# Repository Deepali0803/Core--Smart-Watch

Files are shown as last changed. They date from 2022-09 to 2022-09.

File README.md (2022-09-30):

# Core--Smart-Watch
This is a design of development board for SmartWatch, designed in Eagle Autodesk with SMD and through-hole components.
It is capable of performing some basic functions such as digital read/write, analog signals, I2C and UART communications, with Bluetooth connection, RTC(real-time clock), and OLED display to set alarm and operate easily.

The power consumption in sleep mode is very low, around 1.3mA so the battery could last 2 days.

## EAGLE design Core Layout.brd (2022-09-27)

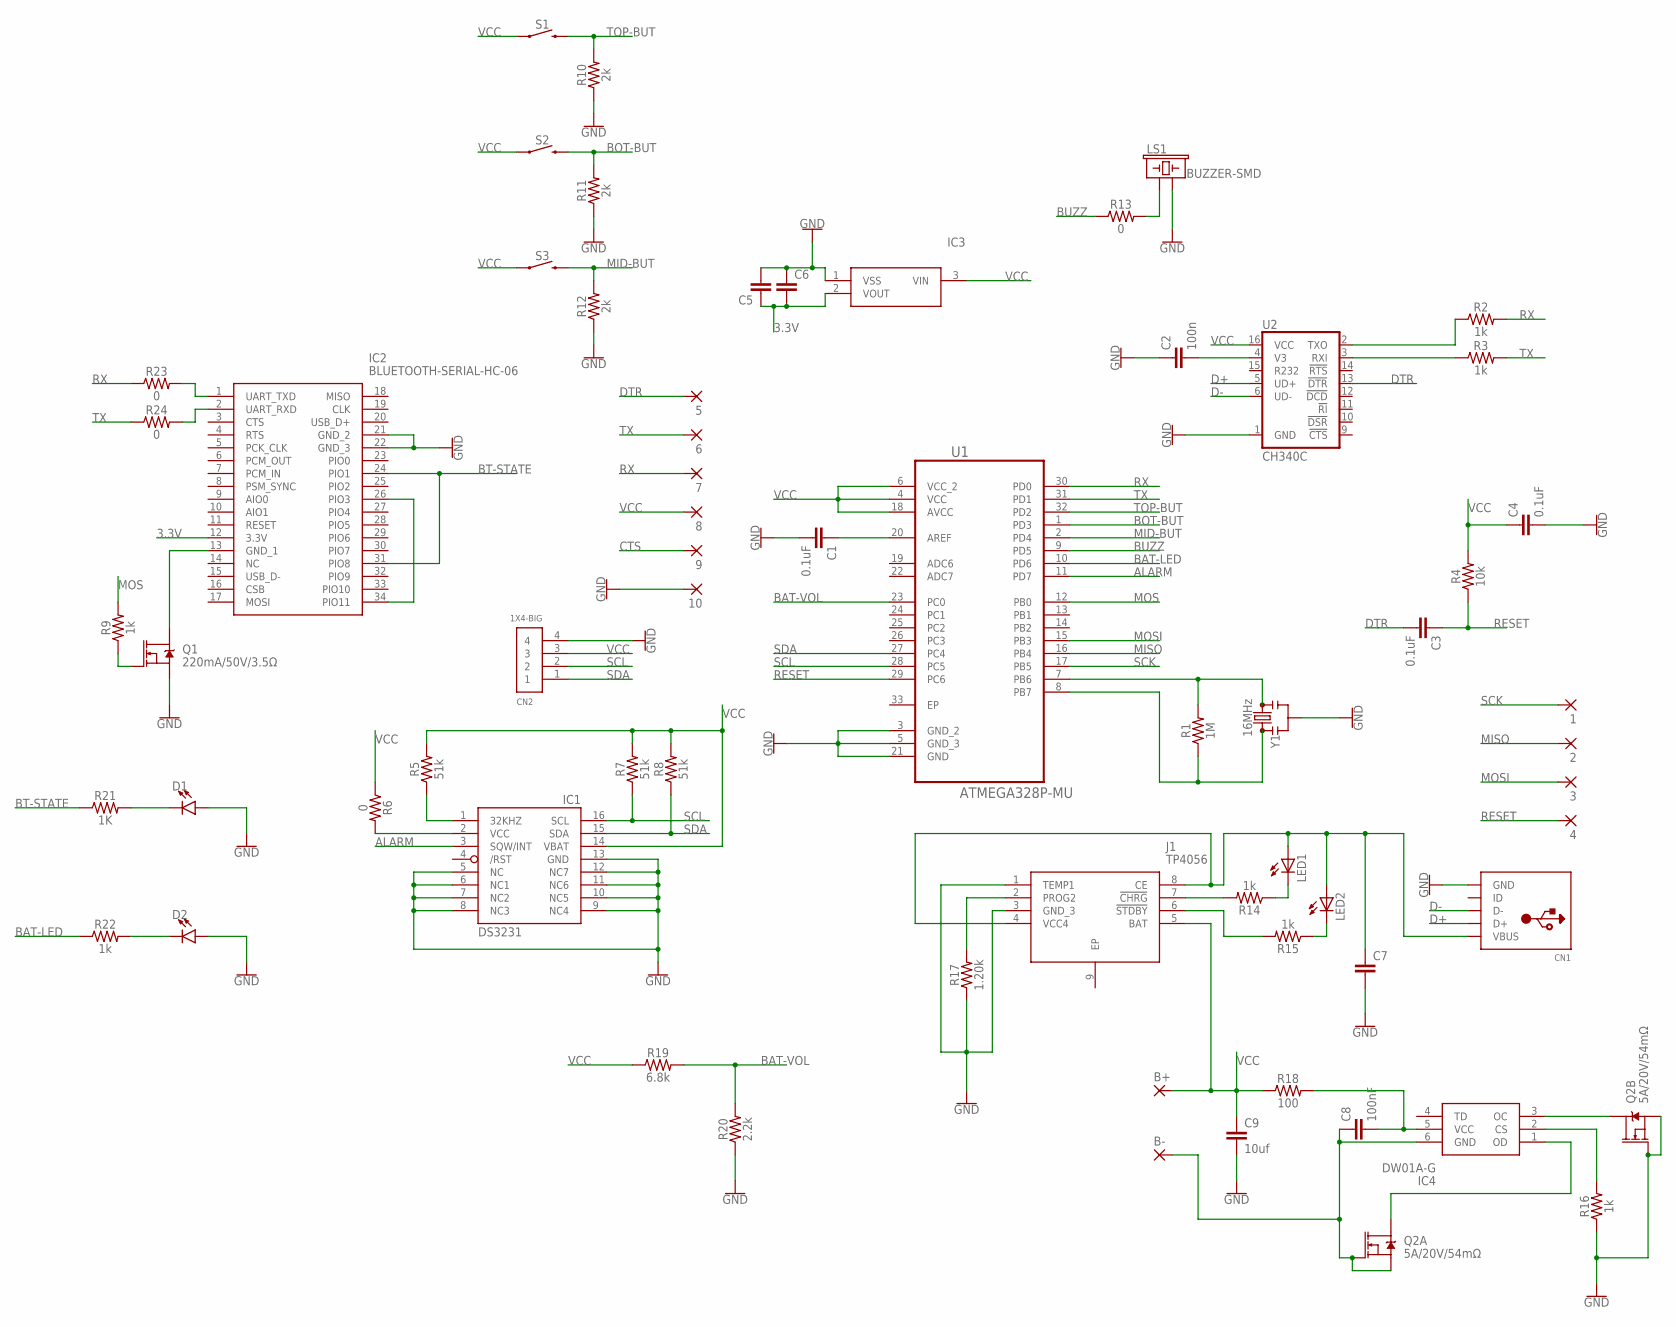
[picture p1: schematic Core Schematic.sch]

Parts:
1, 2, 3, 4, 5, 6, 7, 8, 9, 10: SMD2; SMD1,27-2,54
B+: SMD2; SMD1,27-2,54
B-: SMD2; SMD1,27-2,54
C1, C3, C4: 0.1uF; 0603
C2: 100n; 0603
C5, C6, C7: 4.7PF-0603-50V-5%; 0603
C8: 100nF; 0603
C9: 10uf; 0603
CN1: USBMINIB; USB-MINIB
CN2: 1X4-BIG; 1X04-BIG
D1, D2: LED0603; LED-0603
IC1: DS3231/SO; SO16W
IC2: BLUETOOTH-SERIAL-HC-06; BLUETOOTHSERIALHC06
IC3: XC6206P332MR; SOT95P280X130-3N
IC4: DW01A-G; SOT95P280X135-6N
J1: TP4056; SOIC127P600X175-9N
LED1, LED2: LEDCHIPLED_0805; CHIPLED_0805
LS1: BUZZER-SMD; BUZZER-CCV
Q1: 220mA/50V/3.5Ω; SOT23-3
Q2: 5A/20V/54mΩ; MICROFET_2X2
R1: 1M; 0603
R2, R3, R9, R14, R15, R16, R22: 1k; 0603
R4: 10k; 0603
R5, R7, R8: 51k; 0603
R6, R13, R23, R24: 0; 0603
R10, R11, R12: 2k; 0603
R17: 1.20k; 0603
R18: 100; 0603
R19: 6.8k; 0603
R20: 2.2k; 0603
R21: 1K; 0603
S1, S2, S3: MOMENTARY-SWITCH-SPST-SMD-6.0X3.5MM; TACTILE_SWITCH_SMD_6.0X3.5MM
U1: ATMEGA328P-MU; QFN50P500X500X100-33N
U2: CH340C; SO016
Y1: 16MHz; RESONATOR-SMD-3.2X1.3

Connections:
3.3V: C5.1, C6.2, IC2.12 (3.3V), IC3.2 (VOUT)
ALARM: IC1.3 (SQW/INT), U1.11 (PD7)
BAT-LED: R22.1, U1.10 (PD6)
BAT-VOL: R19.2, R20.2, U1.23 (PC0)
BOT-BUT: R11.2, S2.2, U1.1 (PD3)
BT-STATE: IC2.24 (PIO1), IC2.31 (PIO8), R21.1
BUZZ: R13.1, U1.9 (PD5)
CTS: 9.1
D+: CN1.D+, U2.5 (UD+)
D-: CN1.D-, U2.6 (UD-)
DTR: 5.1, C3.2, U2.13 (!DTR)
GND: 10.1, C1.2, C2.1, C4.2, C5.2, C6.1, C7.2, C9.2, CN1.GND, CN2.4, D1.A, D2.A, IC1.5 (NC), IC1.6 (NC1), IC1.7 (NC2), IC1.8 (NC3), IC1.9 (NC4), IC1.10 (NC5), IC1.11 (NC6), IC1.12 (NC7), IC1.13 (GND), IC2.21 (GND_2), IC2.22 (GND_3), IC3.1 (VSS), J1.1 (TEMP1), J1.3 (GND_3), LS1.- (2), Q1.2 (S), Q2.G2 (G), Q2.S2 (S), R10.1, R11.1, R12.1, R16.1, R17.1, R20.1, U1.3 (GND_2), U1.5 (GND_3), U1.21 (GND), U2.1 (GND), Y1.2
MID-BUT: R12.2, S3.2, U1.2 (PD4)
MISO: 2.1, U1.16 (PB4)
MOS: R9.2, U1.12 (PB0)
MOSI: 3.1, U1.15 (PB3)
unnamed: C1.1, U1.20 (AREF)
unnamed: IC1.1 (32KHZ), R5.1
unnamed: R1.2, U1.7 (PB6), Y1.3
unnamed: R1.1, U1.8 (PB7), Y1.1
unnamed: IC1.2 (VCC), R6.2
unnamed: IC2.13 (GND_1), Q1.3 (D)
unnamed: C2.2, U2.4 (V3)
unnamed: R3.1, U2.3 (RXI)
unnamed: Q1.1 (G), R9.1
unnamed: LS1.+ (1), R13.2
unnamed: R2.1, U2.2 (TXO)
unnamed: J1.6 (!STDBY), R15.2
unnamed: LED2.C, R15.1
unnamed: J1.7 (!CHRG), R14.2
unnamed: LED1.C, R14.1
unnamed: C7.1, CN1.VBUS, J1.4 (VCC4), J1.8 (CE), LED1.A, LED2.A
unnamed: C8.2, IC4.5 (VCC), R18.2
unnamed: B-.1, C8.1, IC4.6 (GND), Q2.G1 (G), Q2.S1 (S)
unnamed: J1.2 (PROG2), R17.2
unnamed: D2.C, R22.2
unnamed: D1.C, R21.2
unnamed: IC2.26 (PIO3), IC2.34 (PIO11)
unnamed: IC4.3 (OC), Q2.D2 (D), Q2.D2_2 (D)
unnamed: IC4.2 (CS), R16.2
unnamed: IC2.1 (UART_TXD), R23.2
unnamed: IC4.1 (OD), Q2.D1 (D), Q2.D1_2 (D)
unnamed: IC2.2 (UART_RXD), R24.2
RESET: 4.1, C3.1, R4.1, U1.29 (PC6)
RX: 7.1, R2.2, R23.1, U1.30 (PD0)
SCK: 1.1, U1.17 (PB5)
SCL: CN2.2, IC1.16 (SCL), R7.1, U1.28 (PC5)
SDA: CN2.1, IC1.15 (SDA), R8.1, U1.27 (PC4)
TOP-BUT: R10.2, S1.2, U1.32 (PD2)
TX: 6.1, R3.2, R24.1, U1.31 (PD1)
VCC: 8.1, B+.1, C4.1, C9.1, CN2.3, IC1.14 (VBAT), IC3.3 (VIN), J1.5 (BAT), R4.2, R5.2, R6.1, R7.2, R8.2, R18.1, R19.1, S1.1, S2.1, S3.1, U1.4 (VCC), U1.6 (VCC_2), U1.18 (AVCC), U2.16 (VCC)

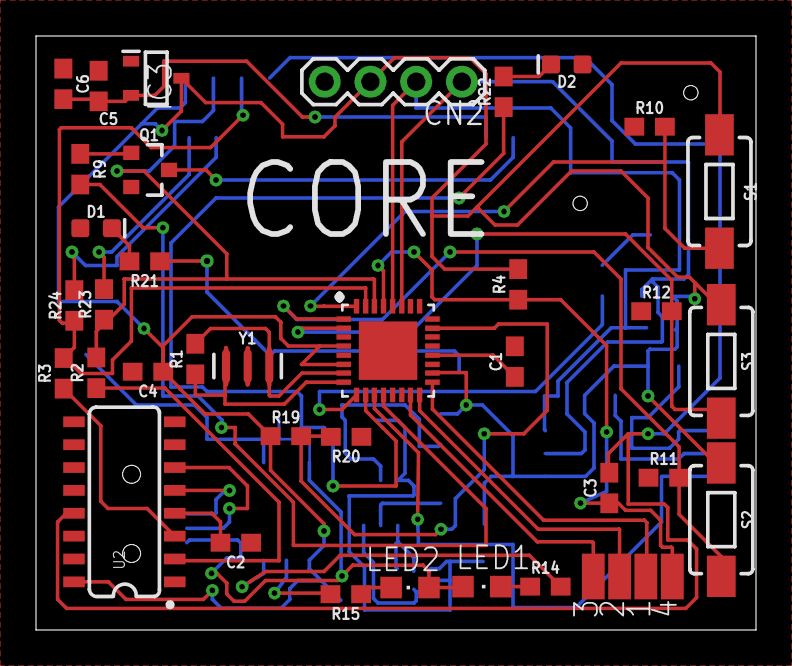
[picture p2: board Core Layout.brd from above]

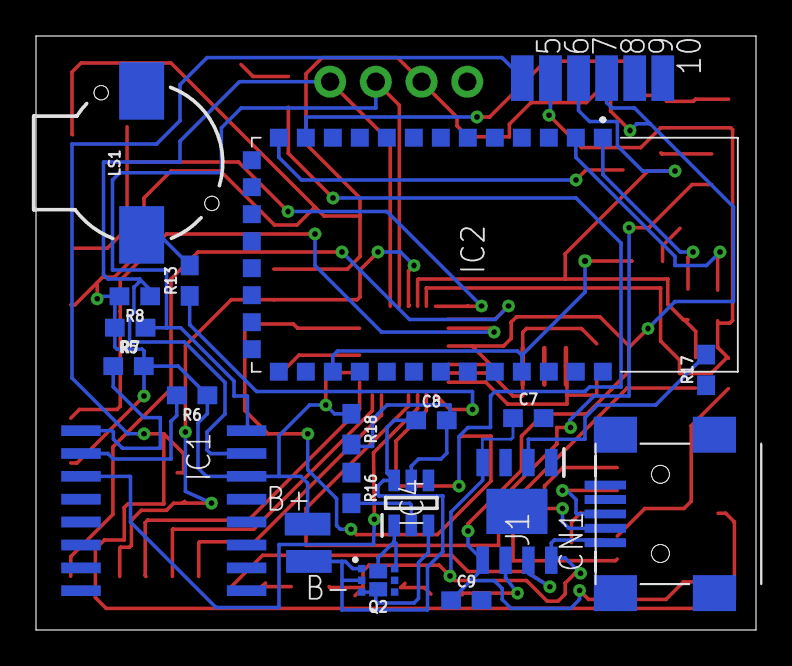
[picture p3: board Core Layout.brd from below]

Board: 2 copper layers, 40.0 x 33.0 mm, 65 parts (26 on the bottom side), 50 nets.

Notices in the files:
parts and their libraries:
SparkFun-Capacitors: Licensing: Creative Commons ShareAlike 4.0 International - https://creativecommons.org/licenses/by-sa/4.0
